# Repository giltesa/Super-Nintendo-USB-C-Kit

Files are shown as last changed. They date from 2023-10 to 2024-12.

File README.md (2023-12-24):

# Super Nintendo: USB-C Kit

The **Super Nintendo: USB-C Kit** is a board that allows to replace the original power connector for a modern and standard USB-C.

**If your original connector is too old or damaged** and you need a new one, or **if you would like to power up your Super Nintendo with a standard USB-C charger**, such as the charger for your **Nintendo Switch**, phone, or laptop, you can do so with this kit.

Moreover, with this board, **you can remove the original, old, and inefficient power converter**. Since the console operates at 5V, you only need the power from USB-C and a regular charger.

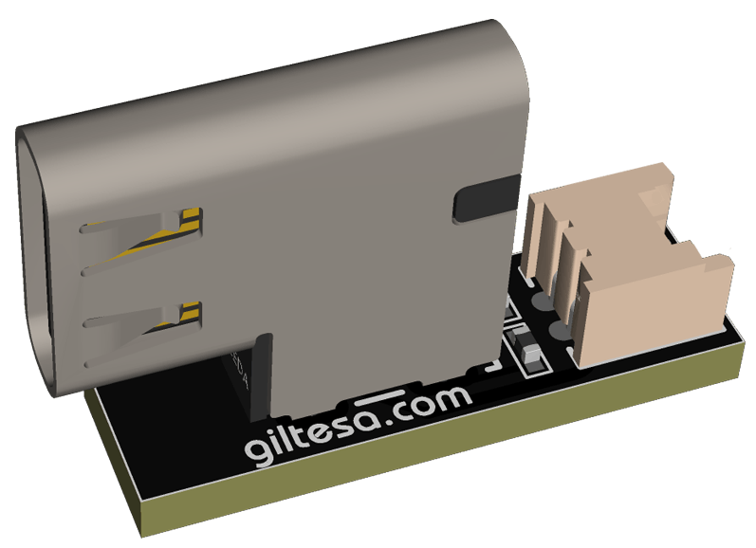
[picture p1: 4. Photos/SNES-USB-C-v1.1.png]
SNES


## Would you like it?

[**Super Nintendo USB-C Kit (EN)**](https://shop.giltesa.com/product/super-nintendo-usb-c-kit/)

## License

This project is licensed under a **Creative Commons** license:
**[Attribution-NonCommercial-ShareAlike 4.0 International (CC BY-NC-SA 4.0) ](https://creativecommons.org/licenses/by-nc-sa/4.0/)**

Check the [LICENSE.md](LICENSE.md) for more information.

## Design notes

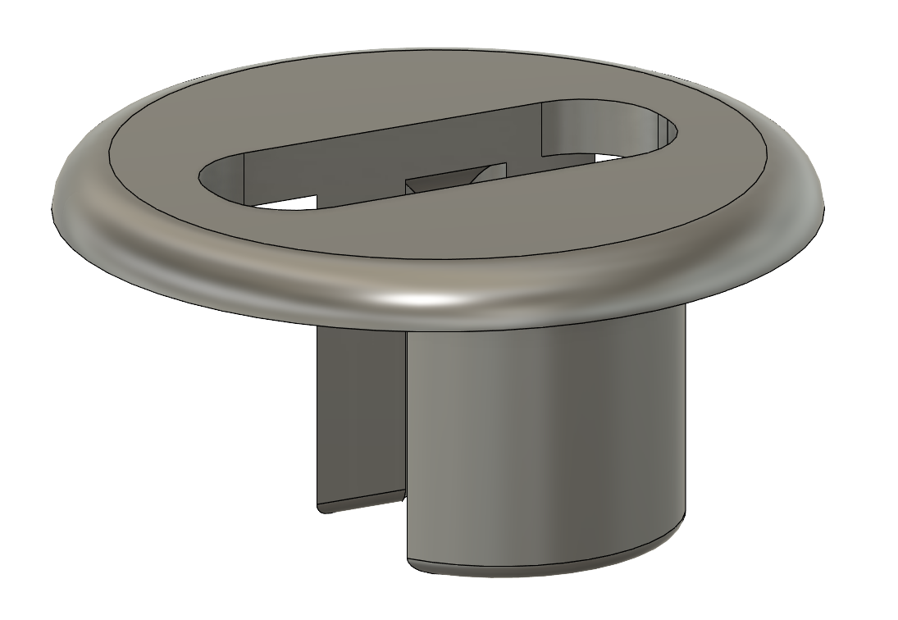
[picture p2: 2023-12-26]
2. Renders, 3D models/Plastic Cap/SNES - USB Cover v21.png

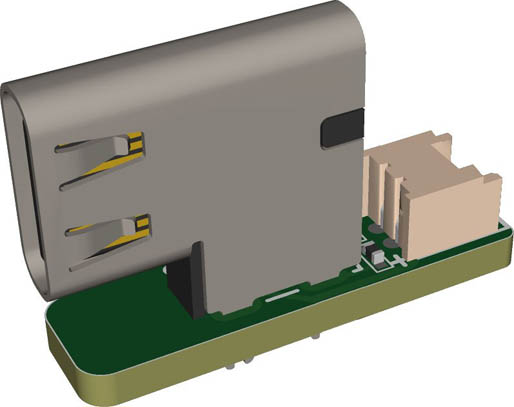
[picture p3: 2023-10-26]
4. Photos/SNES-USB-C-v1.0.jpg

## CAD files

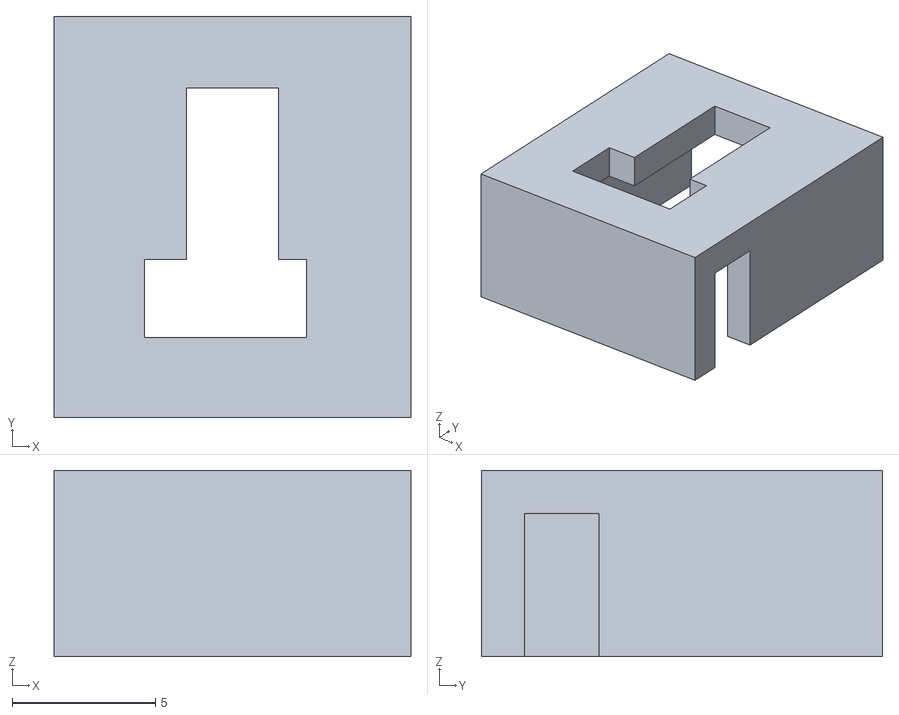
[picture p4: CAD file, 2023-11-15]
2. Renders, 3D models/Cutting Tool/SNES - Back Cutting Tool v11.stl
12.4 x 14.0 x 6.50

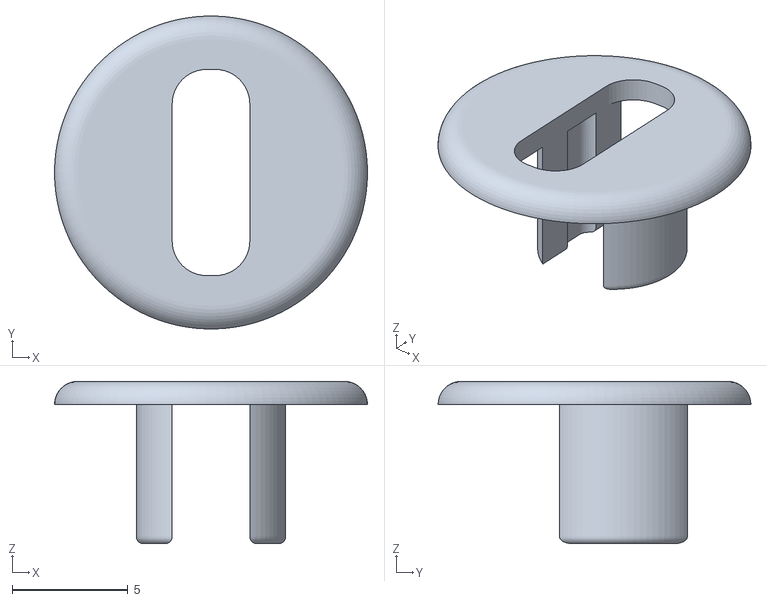
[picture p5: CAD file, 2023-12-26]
2. Renders, 3D models/Plastic Cap/SNES - USB Cover v21.stl
13.5 x 13.5 x 7.00

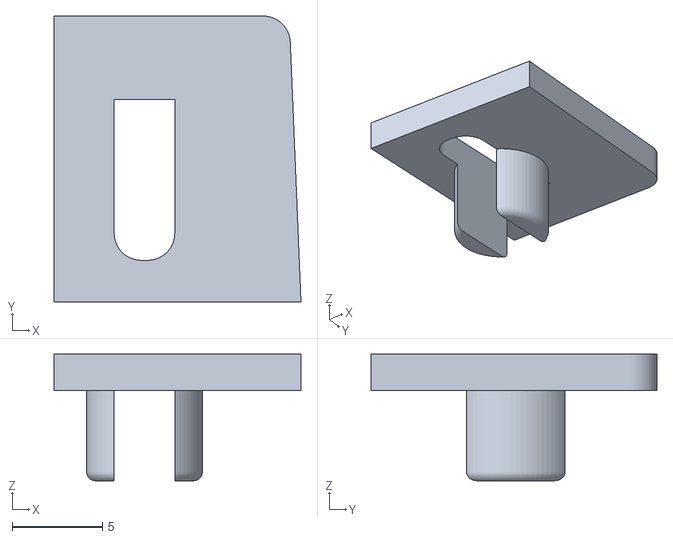
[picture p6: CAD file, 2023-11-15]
2. Renders, 3D models/Cutting Tool/SNES - Front Cutting Tool v12.stl
13.6 x 15.8 x 7.00

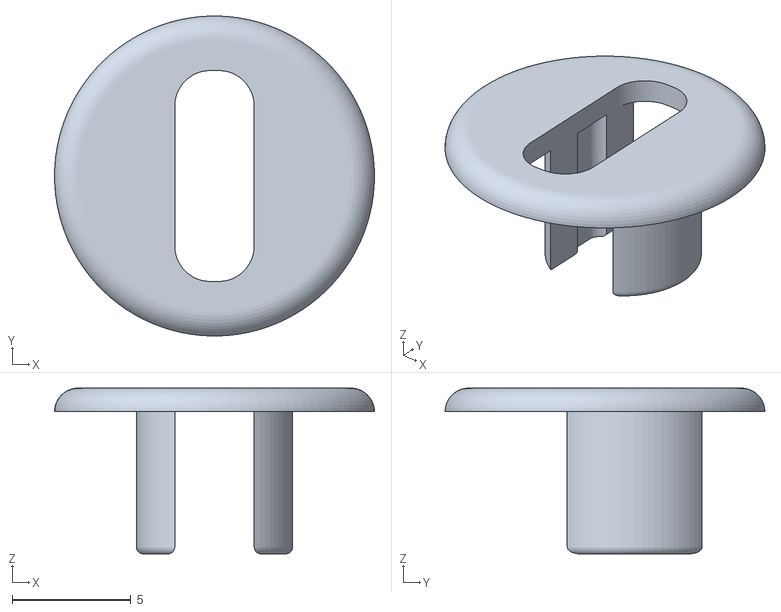
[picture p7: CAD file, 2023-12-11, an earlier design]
2. Renders, 3D models/Plastic Cap/SNES - USB Cover v20.stl
13.5 x 13.5 x 7.00

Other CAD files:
2. Renders, 3D models/Cutting Tool/SNES - Back Cutting Tool v11.f3d
2. Renders, 3D models/Cutting Tool/SNES - Front Cutting Tool v12.f3d
2. Renders, 3D models/Plastic Cap/SNES - USB Cover v21.f3d

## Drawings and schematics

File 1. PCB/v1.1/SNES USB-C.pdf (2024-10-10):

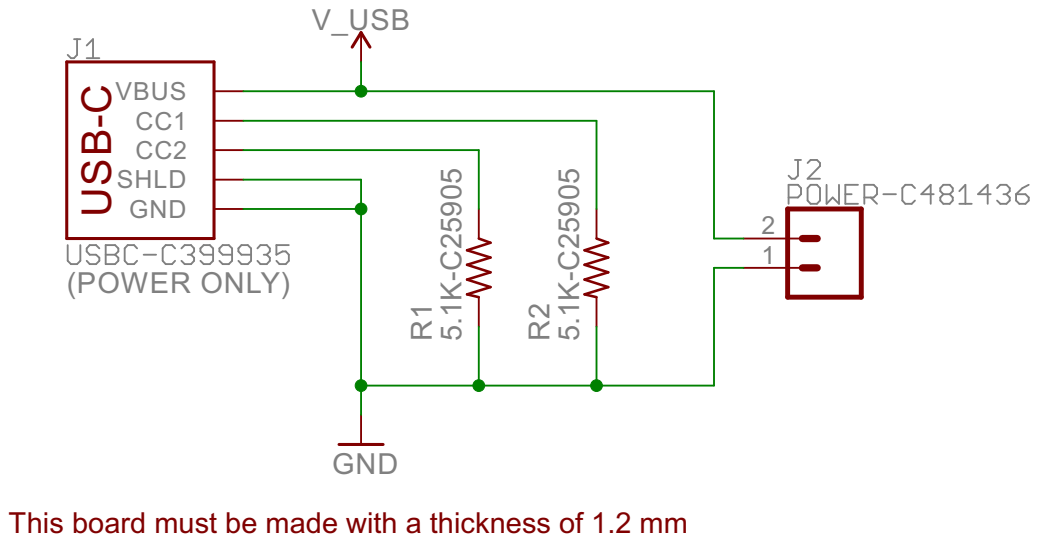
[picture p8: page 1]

This board must be made with a thickness of 1.2 mm

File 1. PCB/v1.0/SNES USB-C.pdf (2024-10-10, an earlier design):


This board must be made with a thickness of 1.2 mm

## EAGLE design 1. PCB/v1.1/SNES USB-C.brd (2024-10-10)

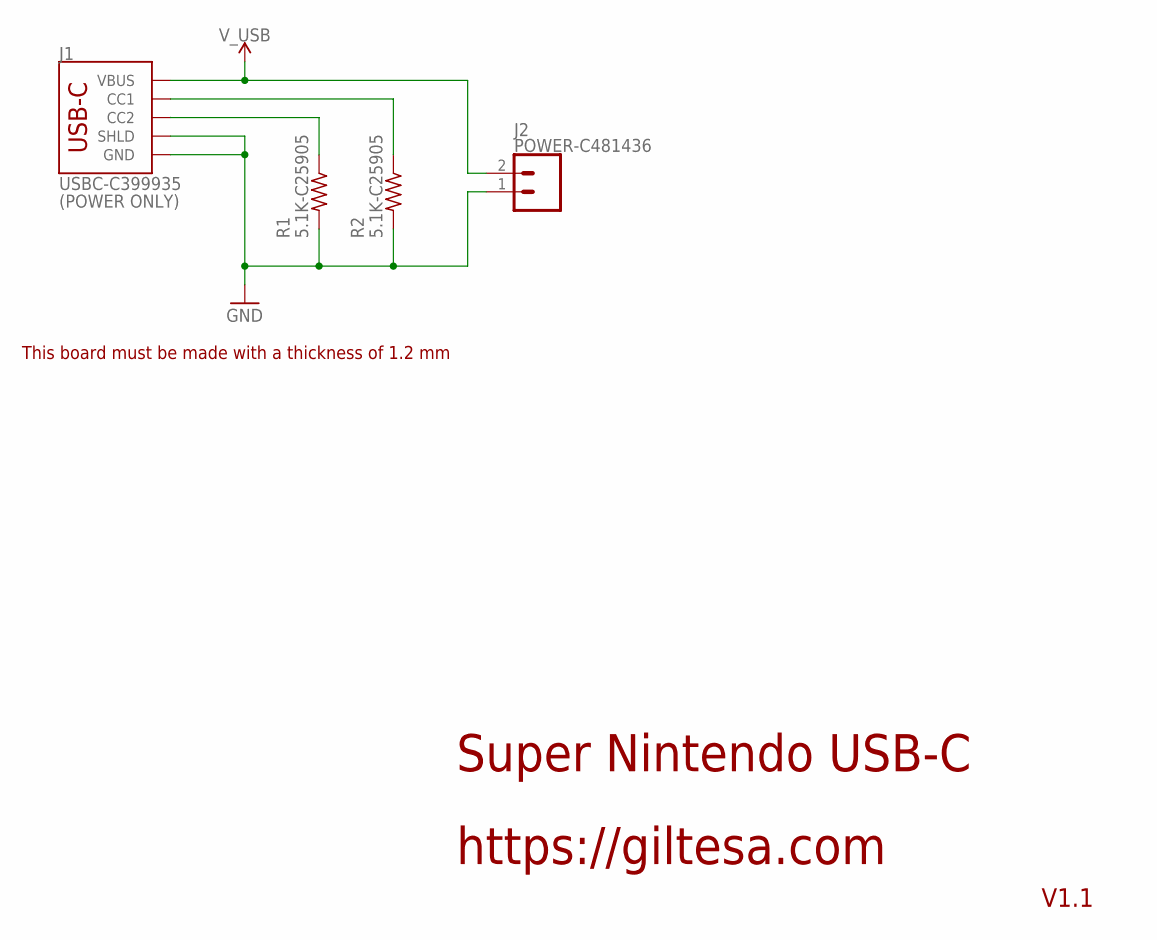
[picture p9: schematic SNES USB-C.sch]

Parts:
J1: USBC-C399935; USB-C_6P_SIDE
J2: POWER-C481436; JST-2-1.25MM_RIGHT
R1, R2: 5.1K-C25905; R0402

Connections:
GND: J1.A12-GND (GND), J1.B12-GND (GND), J1.SHLD1 (SHLD), J1.SHLD2 (SHLD), J1.SHLD3 (SHLD), J1.SHLD4 (SHLD), J2.1, R1.2, R2.2
unnamed: J1.B5 (CC2), R1.1
unnamed: J1.A5 (CC1), R2.1
V_USB: J1.A9-VBUS (VBUS), J1.B9-VBUS (VBUS), J2.2

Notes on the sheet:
Super Nintendo USB-C
https://giltesa.com
V1.1
This board must be made with a thickness of 1.2 mm
(POWER ONLY)

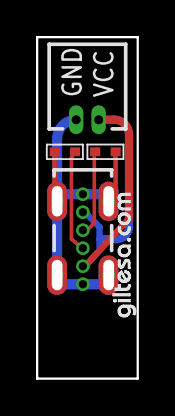
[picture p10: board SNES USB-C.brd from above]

Board: 2 copper layers, 5.6 x 19.0 mm, 5 parts (0 on the bottom side), 4 nets.

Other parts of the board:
U$11: GILTESA.COM_MASK_7MM

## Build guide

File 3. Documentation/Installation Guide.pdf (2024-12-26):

# Super Nintendo USB-C Kit

PRODUCT

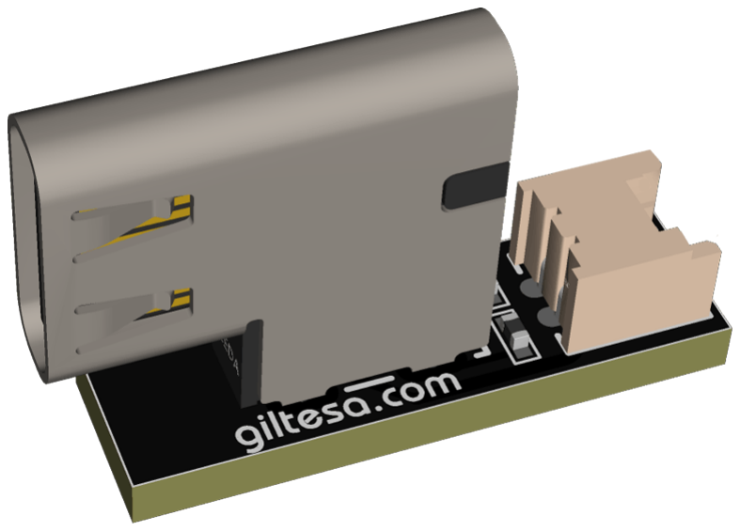
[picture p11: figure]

HTTPS://SHOP.GILTESA.COM/PRODUCT/SUPER-NINTENDO-USB-C-KIT

# PLEASE READ THROUGH THESE INSTRUCTIONS

ENTIRELY BEFORE ATTEMPTING TO INSTALL.

# WARNING: IF YOU ARE NOT COMFORTABLE WITH SOLDERING, OR PERFORMING ANY STEP IN THIS

GUIDE, DO NOT PERFORM THE INSTALL YOURSELF.

# FIND SOMEONE WHO IS COMFORTABLE TO DO IT FOR

YOU.

INDEX

# Description

The Super Nintendo: USB-C Kit is a board that allows to replace the original power connector for a modern and standard USB-C.

If your original connector is too old or damaged and you need a new one, or if you would like to power up your Super Nintendo with a standard USB-C charger, such as the charger for your Nintendo Switch, phone, or laptop, you can do so with this kit.

Moreover, with this board, you can remove the original, old, and inefficient power converter. Since the console operates at 5V, you only need the power from USB-C and a regular charger.

# FEATURES

- Exact shape for Super Nintendo / Super Famicom.
- External power through USB-C. ⁽¹⁾
(1) The USB-C requires trimming of the shell.

# INCLUDED

- 1 USB-C board.
- 1 Power cable.
- 1 Plastic cap for the USB-C board.

# Recommended / REQUIRED (NOT INCLUDED)

- 4.5mm gamebit (https://www.aliexpress.com/item/1005002101234227.html) and phillips screwdrivers.
- Cutting plier. (https://www.aliexpress.com/wholesale?SearchText=Steel+Pliers+Electrical+cutting)
- Cutter. (https://www.aliexpress.com/wholesale?SearchText=Cutter+scalpel)
- Tin soldering iron.
- Tin.
- Flux.
- Isopropyl alcohol.

# Board details

There are 2 pads to solder the included cable. The following explains what each pad is for.

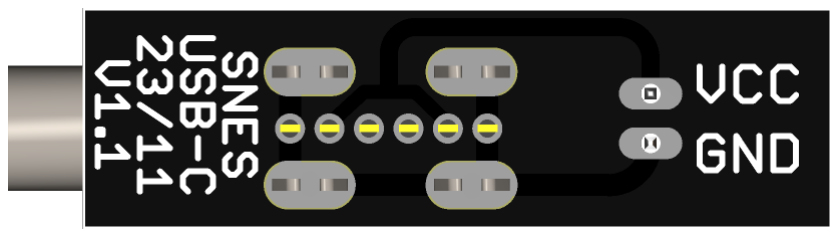
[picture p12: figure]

- VCC: | The +5V line output to power the SNES main board.
- GND: | The ground pad.

NOTE: In versions prior to 1.2, there was a connector for attaching the cable; however, it seemed to be somewhat fragile and caused some issues. Now, instead of a connector, larger pads are included where the cable can be soldered directly.

# INSTALLATION STEPS

Please, carefully read the following steps for a successful installation.

## Pre installation Steps

Before the installation, your SNES may need some extra steps to have it ready for the kit.

1. Disassembly the super Nintendo

Nintendo products in general use two kind of screws. The first one called gamebit to close the shell, and the second one called phillips to hold the main board to the shell.

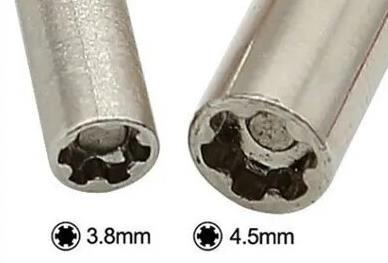
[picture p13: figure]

Gamebit screwdriver
Use the 4.5mm gamebit screwdriver to open the shell and remove the 6 gamebit screws.

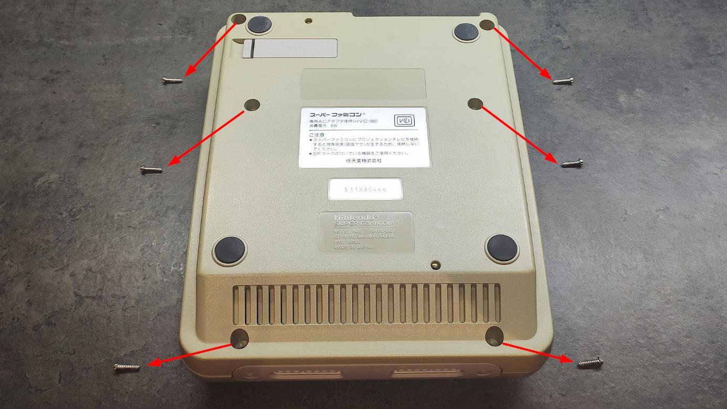
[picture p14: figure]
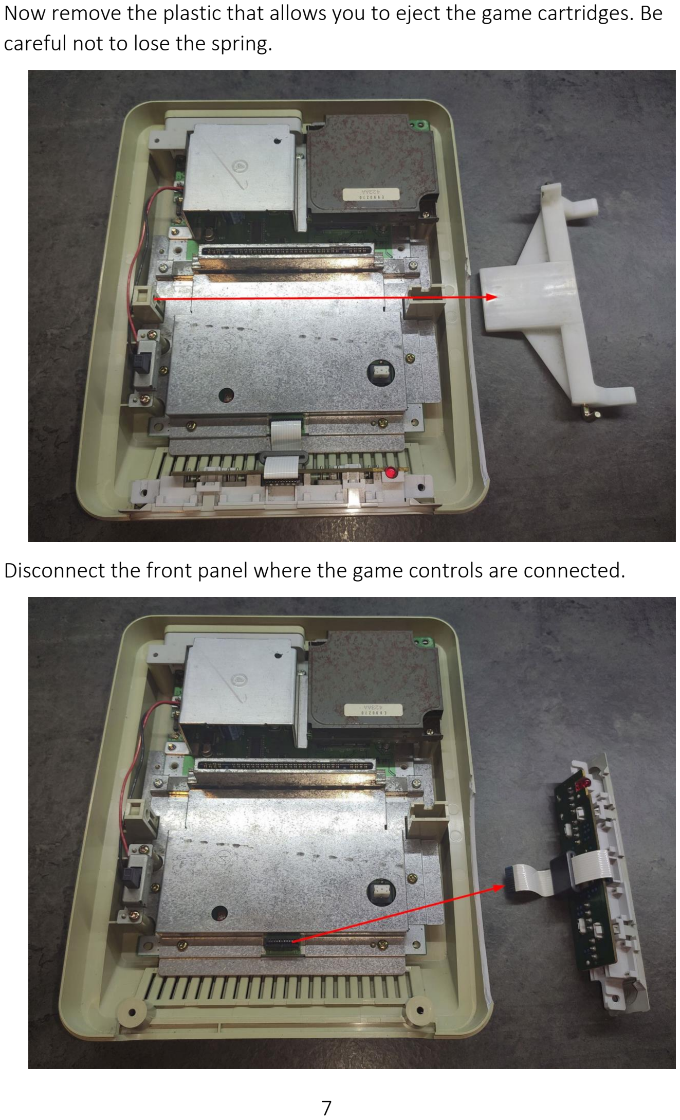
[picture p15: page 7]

Now remove the plastic that allows you to eject the game cartridges. Be careful not to lose the spring.

Disconnect the front panel where the game controls are connected.

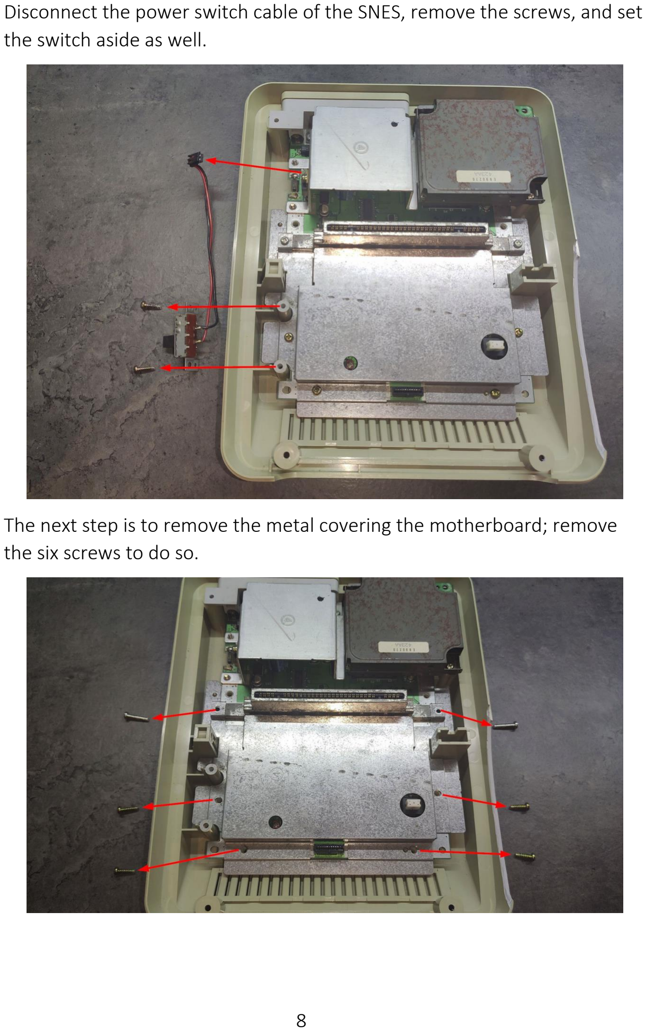
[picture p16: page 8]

Disconnect the power switch cable of the SNES, remove the screws, and set the switch aside as well.

The next step is to remove the metal covering the motherboard; remove the six screws to do so.

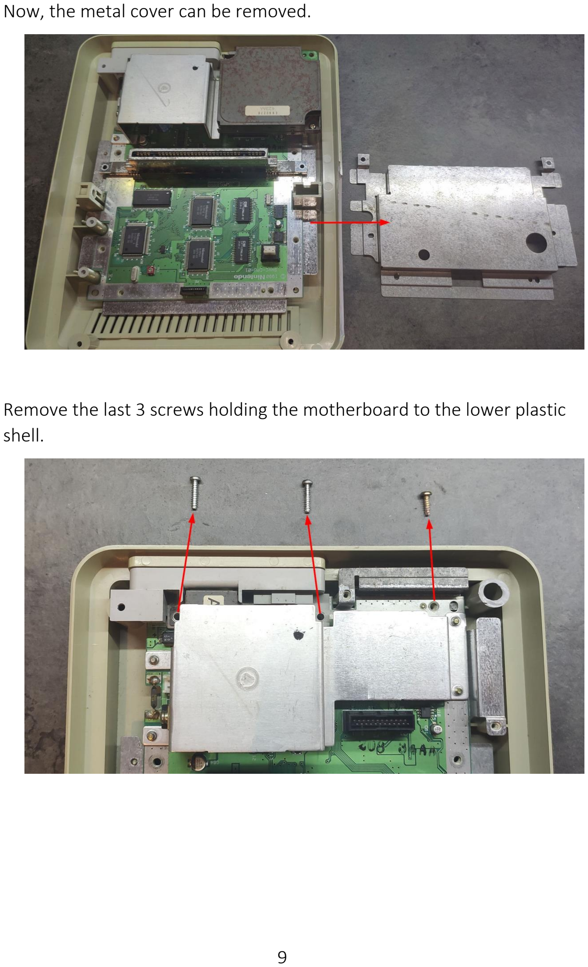
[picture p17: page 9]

Now, the metal cover can be removed.

Remove the last 3 screws holding the motherboard to the lower plastic shell.

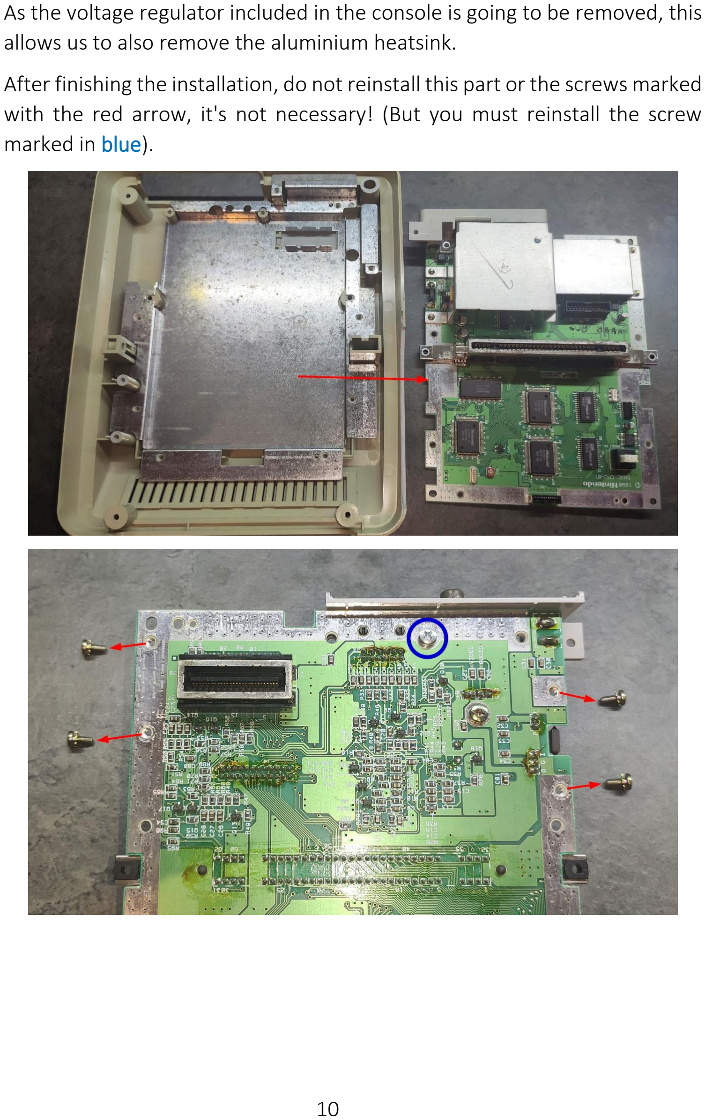
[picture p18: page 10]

As the voltage regulator included in the console is going to be removed, this allows us to also remove the aluminium heatsink.

After finishing the installation, do not reinstall this part or the screws marked with the red arrow, it's not necessary! (But you must reinstall the screw marked in blue).

There is one more screw on the left side; this screw makes the voltage regulator make contact with the heat sink. Remove the screw.

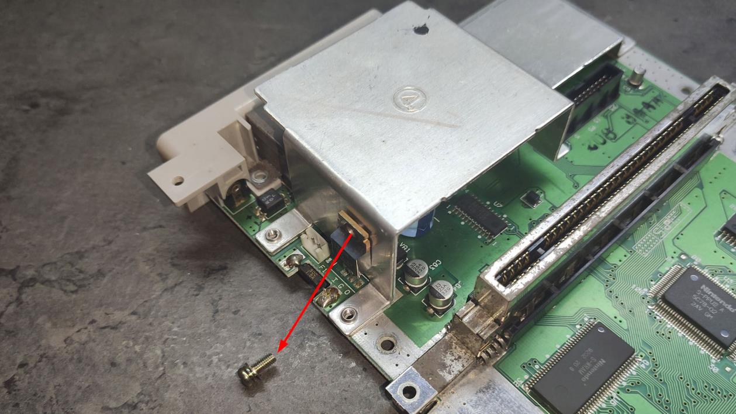
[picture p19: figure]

## installation Steps

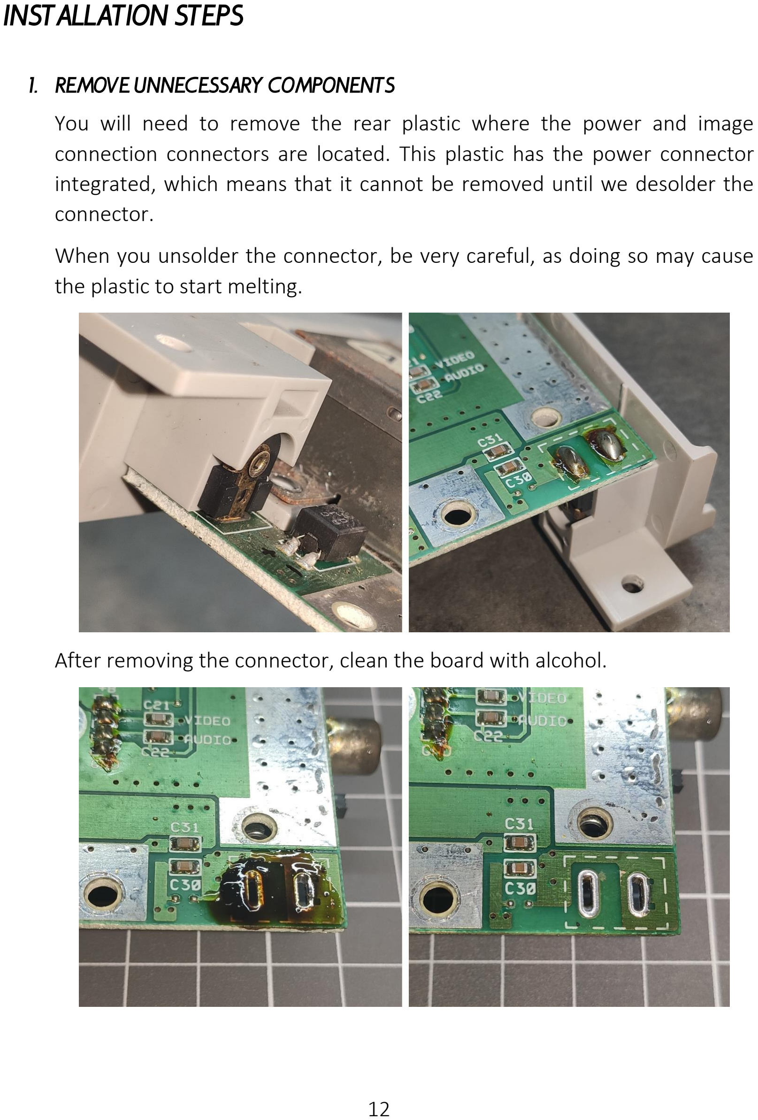
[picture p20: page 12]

1. Remove unnecessary components

You will need to remove the rear plastic where the power and image connection connectors are located. This plastic has the power connector integrated, which means that it cannot be removed until we desolder the connector.

When you unsolder the connector, be very careful, as doing so may cause the plastic to start melting.

After removing the connector, clean the board with alcohol.

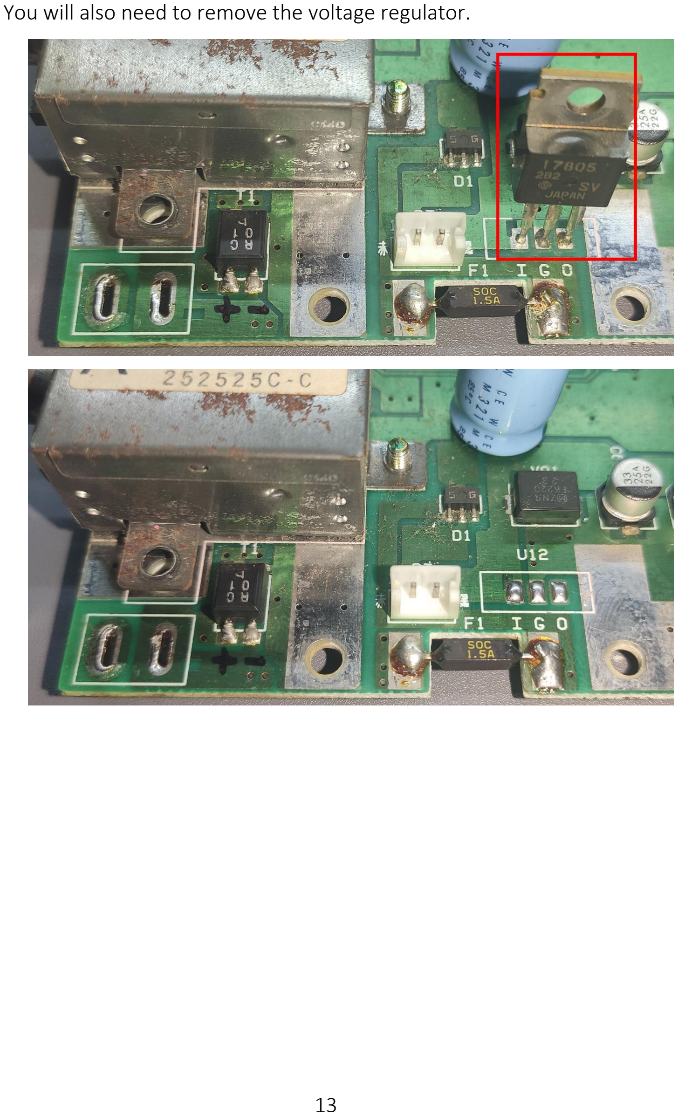
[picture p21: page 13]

You will also need to remove the voltage regulator.

2. Cable installation

Now you can solder the included cable in the kit as follows, making sure that the red wire and the black wire are securely soldered in the correct positions.

Furthermore, if you notice, the surplus cable has been used to create a bridge between the I (INPUT) and O (OUTPUT) pins of the voltage regulator.

(Since the SNES is now powered with 5V, a voltage regulator from 10V to 5V is no longer necessary. That's why a bridge is created between its input and output)

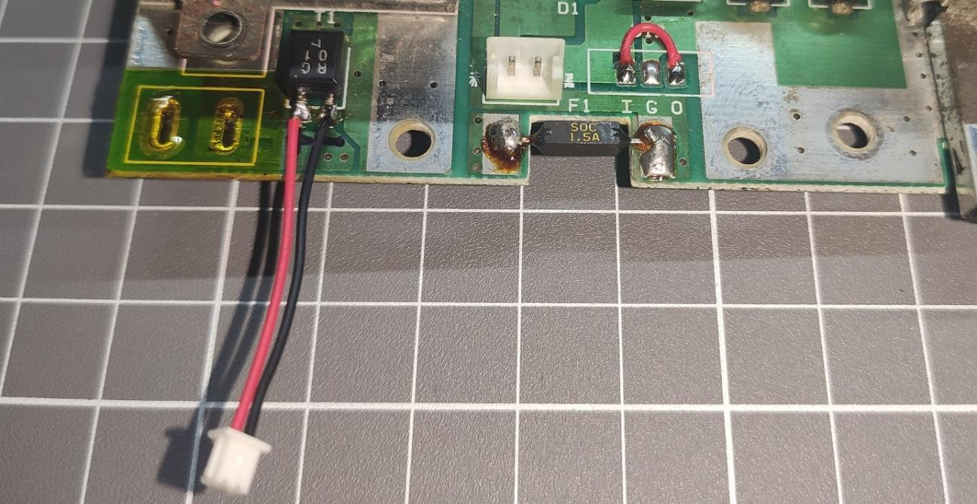
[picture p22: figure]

IMPORTANT NOTE: It seems that some models of SNES have reversed polarity. Before soldering the cable, make sure that the red cable is connected to the VCC pin of the SNES, likewise, ensure that the black cable is connected to the GND of the SNES.

One way to verify where to solder each cable is to check which of the cables is connected to the console's ground plane. For example, in my SNES, all these points have continuity and cause the speaker of my multimeter to beep (when it is set in continuity test mode).

Then, check which pin is GND, and by process of elimination, you'll know which one is VCC.

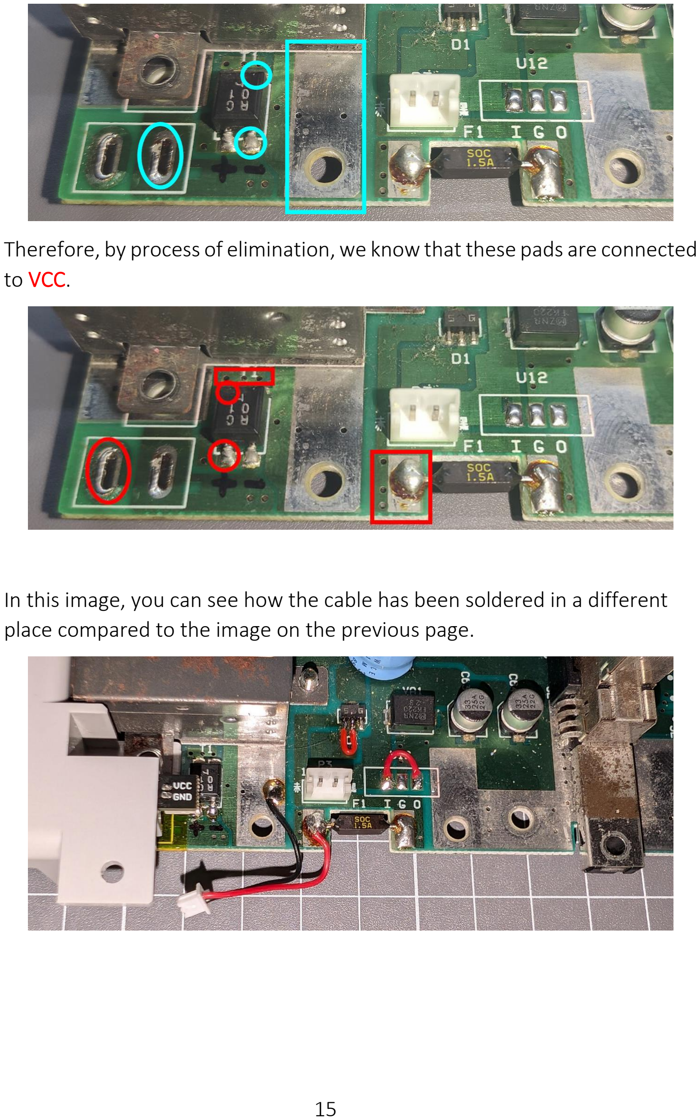
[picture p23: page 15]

Therefore, by process of elimination, we know that these pads are connected to VCC.

In this image, you can see how the cable has been soldered in a different place compared to the image on the previous page.

Possibly, you may also need to bridge these two points because that component (a diode) causes the voltage to drop between 0.3 to 0.5V, resulting in the SNES receiving only 4.5V instead of 5V.

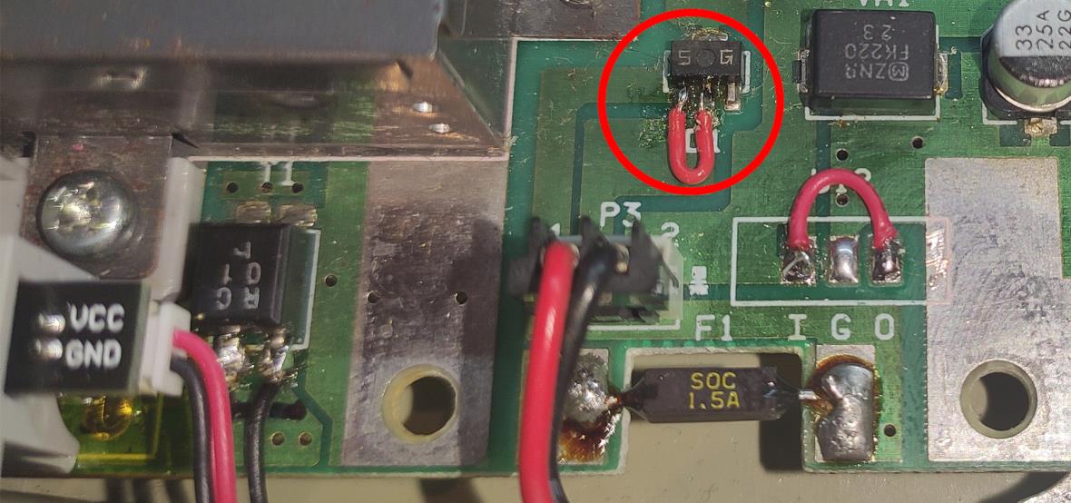
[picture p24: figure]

At that point, if you want, you can connect the USB-C board and test that the console works.

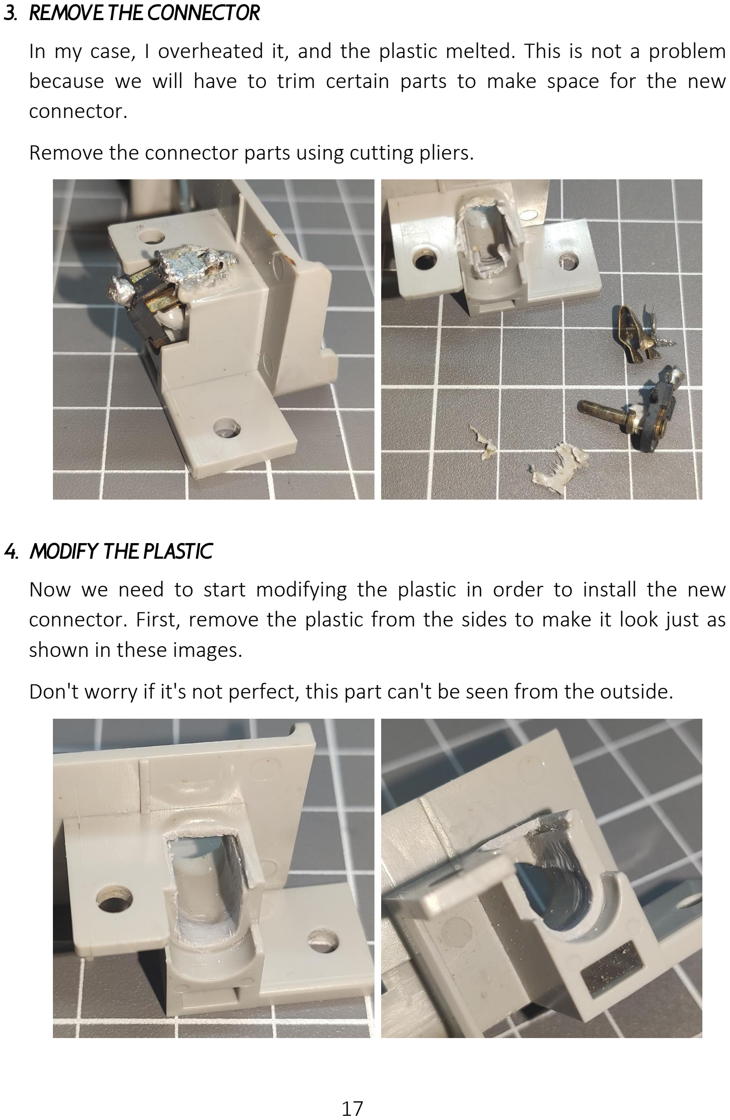
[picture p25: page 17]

3. Remove the connector

In my case, I overheated it, and the plastic melted. This is not a problem because we will have to trim certain parts to make space for the new connector.

Remove the connector parts using cutting pliers.

4. Modify the plastic

Now we need to start modifying the plastic in order to install the new connector. First, remove the plastic from the sides to make it look just as shown in these images.

Don't worry if it's not perfect, this part can't be seen from the outside.

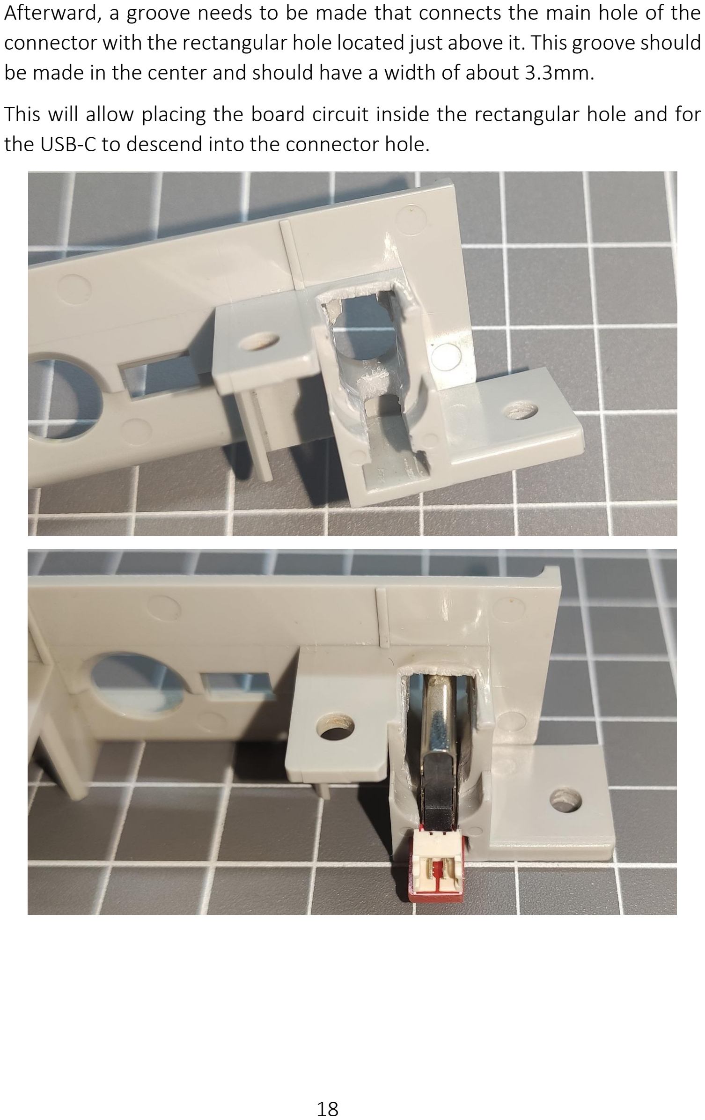
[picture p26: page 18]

Afterward, a groove needs to be made that connects the main hole of the connector with the rectangular hole located just above it. This groove should be made in the center and should have a width of about 3.3mm.

This will allow placing the board circuit inside the rectangular hole and for the USB-C to descend into the connector hole.

Finally, enlarge the front hole so that the USB-C can protrude. Place the board in its position, and you'll notice that the hole is not large enough. Gradually file the plastic and test with the board until it is large enough.

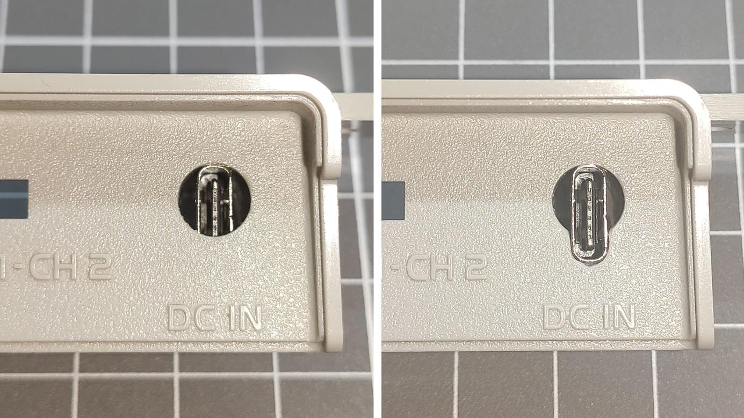
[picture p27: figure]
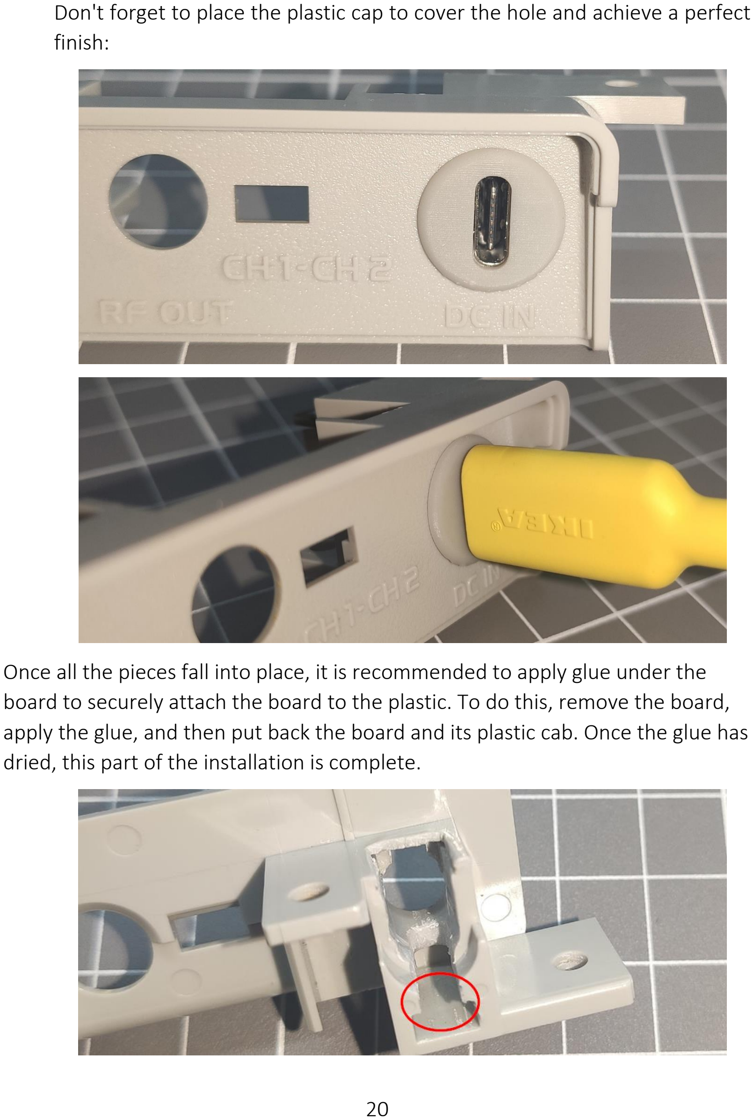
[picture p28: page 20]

Don't forget to place the plastic cap to cover the hole and achieve a perfect finish:

Once all the pieces fall into place, it is recommended to apply glue under the board to securely attach the board to the plastic. To do this, remove the board, apply the glue, and then put back the board and its plastic cab. Once the glue has dried, this part of the installation is complete.

5. Done!

Follow the steps backward, placing each thing in its place, and the installation will be complete!

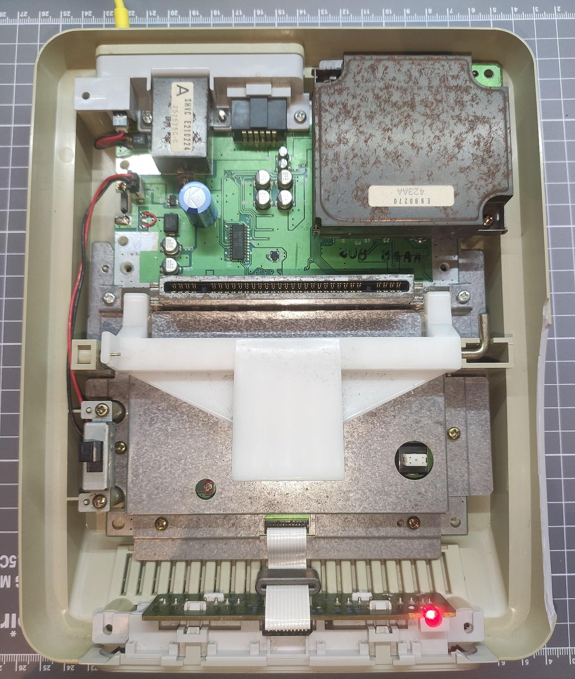
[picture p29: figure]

# Frequently Asked Questions - FAQ

Nothing yet

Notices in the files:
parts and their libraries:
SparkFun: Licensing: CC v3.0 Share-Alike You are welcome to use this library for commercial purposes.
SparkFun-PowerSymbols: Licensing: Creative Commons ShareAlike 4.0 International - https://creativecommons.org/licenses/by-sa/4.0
